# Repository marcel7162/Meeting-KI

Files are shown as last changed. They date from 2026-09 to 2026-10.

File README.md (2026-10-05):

# Meeting-KI 🎙️🤖

Ein **ESP32-S3** mit **INMP441-Mikrofon**, das Meetings mithört, den Ton an einen
kleinen Python-Server streamt, dort automatisch transkribiert und am Ende mit
**Claude** eine Zusammenfassung schreibt.

---

## Wie es funktioniert

```
┌──────────────┐   I2S    ┌───────────────┐   WLAN / TCP   ┌────────────────────────┐
│   INMP441    │ ───────► │   ESP32-S3    │ ─────────────► │      Python-Server      │
│  (Mikrofon)  │          │  (Firmware)   │   16 kHz PCM   │                        │
└──────────────┘          └───────────────┘                │  1. Audio → WAV        │
                                                            │  2. Whisper → Text     │
                                                            │  3. Claude → Zusammen- │
                                                            │     fassung (.md)      │
                                                            └────────────────────────┘
```

1. Das **INMP441** liefert digitales Audio über I2S an den **ESP32**.
2. Die **Firmware** verbindet sich beim Einschalten mit dem WLAN und dem Server
   und **startet sofort** die Aufnahme; sie streamt durchgehend
   16-kHz-Mono-PCM per TCP an den Server.
3. Der **Server** puffert den Ton. Wird der ESP vom Strom getrennt, erkennt der
   Server den Abbruch und **beendet die Aufnahme automatisch**.
4. Dann wird das Audio als WAV gespeichert, mit **faster-whisper** lokal
   transkribiert und zu einer strukturierten Zusammenfassung verarbeitet
   (Claude oder lokal via Ollama/HuggingFace).

Transkription läuft **lokal** (Datenschutz – der Rohton verlässt dein Netz
nicht). Nur der fertige Transkript-Text geht zur Zusammenfassung an Claude.

---

## Hardware & Verkabelung

Board: **ESP32-S3 Zero** (Waveshare). Alle genutzten Signal-Pins liegen auf der
vorderen Stiftleiste (GPIO1–GPIO13); die WS2812-Status-LED ist fest onboard.

### Mikrofon (INMP441)

| INMP441 Pin | Funktion | ESP32-S3 Zero |
|---|---|---|
| VDD | 3,3 V | 3V3 |
| GND | Masse | GND |
| SCK | I2S Bit-Clock (BCLK) | GPIO 4 |
| WS | I2S Word-Select (LRCLK) | GPIO 5 |
| SD | I2S Daten (DOUT) | GPIO 6 |
| L/R | Kanalwahl | GPIO 3 |

Der **L/R-Pin wird hier vom ESP32 über GPIO3 getrieben** (nicht fest an GND).
Die Firmware legt GPIO3 auf **LOW** = linker Kanal (passend zur I2S-Konfig). Wenn
du lieber fest verdrahten willst, kannst du `L/R` auch direkt an GND legen – dann
ist GPIO3 frei.

### Bedienung: nur über Strom (keine Knöpfe)

- **Strom an** → der ESP verbindet sich mit WLAN und Server und **startet sofort
  die Aufnahme**, streamt dann durchgehend.
- **Strom weg** (Akku/USB trennen) → der Server erkennt den Abbruch und
  **beendet + wertet die Aufnahme automatisch aus** (WAV + Transkript +
  Zusammenfassung).

Es gibt keine Taster. Ein „Einschalten bis Ausschalten" = ein Meeting.

### Status-LED (WS2812, onboard auf GPIO21)

| Farbe | Bedeutung |
|---|---|
| 🔴 rot blinkend | kein WLAN |
| 🟠 orange blinkend | WLAN ok, aber kein Server |
| 🔴 rot (dauerhaft) | verbunden, Aufnahme läuft / streamt |

> Alle GPIO-Nummern (und Helligkeit/Farblogik) sind in `firmware/src/config.h`
> konfigurierbar. Nutzt du ein anderes Board ohne WS2812, setze
> `STATUS_LED_IS_WS2812 0` (einfache Ein/Aus-LED) oder `STATUS_LED_PIN -1` (aus).

**Wichtig:** Das INMP441 wird mit **3,3 V** betrieben, nicht mit 5 V.

### Alternatives Board: ESP32-C3 Super Mini

Funktioniert genauso (WLAN + 1× I2S). Unterschiede: andere Pins und die
**einfache Onboard-LED auf GPIO8 (active-low)** statt WS2812.

| Signal | ESP32-C3 Super Mini |
|---|---|
| INMP441 SCK | GPIO 4 |
| INMP441 WS | GPIO 5 |
| INMP441 SD | GPIO 6 |
| INMP441 L/R | GPIO 3 |
| Status-LED | GPIO 8 (onboard, active-low) |

In `firmware/src/config.h` die C3-Werte eintragen (Vorlage steht im unteren Teil
von `config.h.example`), insbesondere:
`STATUS_LED_IS_WS2812 0`, `STATUS_LED_ACTIVE_LOW 1`, `STATUS_LED_PIN 8`.
Flashen mit dem passenden Board-Env:

```bash
pio run -e esp32-c3-supermini --target upload
```

> VDD des INMP441 weiterhin an **3,3 V**.

---

## Teil 1 – Firmware (ESP32-S3 Zero)

Die Firmware ist ein [PlatformIO](https://platformio.org/)-Projekt (Board-Env
`esp32-s3-zero`).

```bash
cd firmware
cp src/config.h.example src/config.h   # dann config.h ausfüllen
# WLAN-Zugang und Server-IP in config.h eintragen
pio run --target upload
pio device monitor        # zum Mitlesen der seriellen Ausgabe
```

> **Flashen klappt nicht?** Der ESP32-S3 Zero lässt sich in den Download-Modus
> zwingen: **BOOT gedrückt halten**, kurz **RESET** tippen (oder USB einstecken),
> BOOT loslassen – dann erneut `pio run --target upload`.

In `src/config.h` trägst du ein:
- `WIFI_SSID` / `WIFI_PASSWORD` – dein WLAN
- `SERVER_HOST` – IP-Adresse des Rechners, auf dem der Python-Server läuft
- `SERVER_PORT` – Port (Standard `8888`)

Die Firmware verbindet sich automatisch wieder, wenn WLAN oder Server-Verbindung
abbrechen. Die Onboard-LED zeigt den Status (siehe Kommentare in `main.cpp`).

---

## Teil 2 – Server (Python)

> **Python-Version beachten:** `faster-whisper` braucht `ctranslate2`, das nur
> für **64-bit-Python 3.9–3.12** fertige Pakete hat. Mit **Python 3.13/3.14**
> oder 32-bit-Python schlägt `pip install` fehl (siehe
> [Problembehebung](#problembehebung)). Prüfen mit `python --version`.

**Windows** (PowerShell), Python von https://www.python.org/ vorausgesetzt:

```powershell
cd server
python -m venv .venv
.\.venv\Scripts\Activate.ps1
pip install -r requirements.txt

copy .env.example .env     # dann .env ausfüllen (ANTHROPIC_API_KEY!)
python server.py
```

> Falls PowerShell das Aktivieren blockiert („… kann nicht geladen werden …"),
> einmalig erlauben:
> `Set-ExecutionPolicy -Scope CurrentUser RemoteSigned`

**macOS / Linux:**

```bash
cd server
python3 -m venv .venv && source .venv/bin/activate
pip install -r requirements.txt

cp .env.example .env       # dann .env ausfüllen (ANTHROPIC_API_KEY!)
python server.py
```

In `.env` trägst du ein:
- `ENABLE_SUMMARY` – `true`/`false` (Zusammenfassung an/aus)
- `SUMMARY_BACKEND` – `claude` | `huggingface` | `none` (siehe unten)
- `ANTHROPIC_API_KEY` – Claude-Schlüssel (nur bei `SUMMARY_BACKEND=claude`)
- `WHISPER_MODEL` – z. B. `base`, `small`, `medium` (Standard: `small`)
- weitere Optionen siehe `.env.example`

### Zusammenfassungs-Backend wählen

| `SUMMARY_BACKEND` | Was passiert | Claude nötig? | Qualität | Zusätzliches Setup |
|---|---|---|---|---|
| `claude` | strukturierte Zusammenfassung via Anthropic-API | ja (API-Key) | ★★★★ | – |
| `ollama` | starkes lokales LLM, **strukturiert** (Überblick, Entscheidungen, To-dos) | **nein** | ★★★☆ | Ollama + Modell |
| `huggingface` | kleines lokales Modell, kompakt & **unstrukturiert** | **nein** | ★★ | `requirements-local-summary.txt` |
| `none` | keine Zusammenfassung, nur Transkript | nein | – | – |

Für **starke, strukturierte Zusammenfassungen ohne Claude** ist `ollama`
die beste Wahl (siehe nächster Abschnitt).

> **Nur transkribieren:** `ENABLE_SUMMARY=false` (oder `SUMMARY_BACKEND=none`) –
> dann entsteht nur das Transkript, kein KI-Aufruf. Die Transkription läuft
> ohnehin komplett lokal (faster-whisper).

### Starke lokale Zusammenfassung ohne Claude (empfohlen: Ollama)

Das `ollama`-Backend nutzt ein echtes Instruct-LLM lokal und liefert dieselbe
strukturierte Gliederung wie Claude (Überblick, Entscheidungen, To-dos …) –
ohne Internet und ohne API-Key. Es braucht **keine** zusätzlichen Python-Pakete.

1. **Ollama installieren:** https://ollama.com/download
2. **Modell laden** (einmalig):
   ```bash
   ollama pull qwen2.5:14b-instruct
   ```
3. In `.env`:
   - `SUMMARY_BACKEND=ollama`
   - `OLLAMA_MODEL=qwen2.5:14b-instruct` (Standard)

Das war's – danach wie gewohnt `python process_file.py ...` bzw. den Server nutzen.

**Andere Modelle:** leichter/schneller `qwen2.5:7b-instruct` oder `llama3.1:8b`;
stärker (mehr RAM/VRAM, langsamer) `qwen2.5:32b-instruct` (jeweils vorher
`ollama pull`). Faustregel RAM/VRAM: 7B ≈ 6–8 GB, 14B ≈ 10–12 GB, 32B ≈ 20 GB+.
Auf CPU läuft es, dauert aber spürbar länger – für lange Meetings fasst das
Backend automatisch abschnittsweise zusammen (Map-Reduce).

### Komplett ohne Claude (kleines Modell via HuggingFace)

Alternativ ein kleines, schnelles Summarizer-Modell lokal (ohne Ollama):

```bash
pip install -r requirements-local-summary.txt   # transformers + torch (mehrere hundert MB)
```

In `.env`: `SUMMARY_BACKEND=huggingface` (optional `HF_SUMMARY_MODEL=...`).

> ⚠️ **Erwartung:** Dieses kleine Modell liefert nur eine kompakte,
> **unstrukturierte** Zusammenfassung – keine Abschnitte wie Entscheidungen/
> To-dos. Für Struktur ohne Claude nimm `ollama`.

Für **Sprecher-Trennung** zusätzlich `ENABLE_DIARIZATION=true` +
`HUGGINGFACE_TOKEN` setzen (siehe nächster Abschnitt) – sie lässt sich mit
jedem Zusammenfassungs-Backend kombinieren.

### Bedienung

Der Server nimmt die TCP-Verbindung des ESP32 automatisch an. Gesteuert wird
**über den Strom**:

- **ESP einschalten** → verbindet sich und nimmt sofort auf (LED **rot**).
- **ESP vom Strom trennen** → der Server erkennt den Abbruch (sauberes
  TCP-Ende oder Watchdog nach ein paar Sekunden ohne Audio) und erzeugt
  automatisch WAV + Transkript + Zusammenfassung.

Ersatzweise geht es auch über die Tastatur im Server-Fenster:

| Taste | Aktion |
|---|---|
| `s` + Enter | Aufnahme **starten** |
| `e` + Enter | Aufnahme **beenden** → WAV + Transkript + Zusammenfassung |
| `q` + Enter | Server beenden |

Nach dem Stoppen entstehen:
- `recordings/meeting_<zeitstempel>.wav` – der Mitschnitt
- `summaries/meeting_<zeitstempel>.md` – Transkript **und** Zusammenfassung

### Vorhandene Aufnahme nachträglich verarbeiten

Du kannst eine bereits aufgenommene WAV **ohne neue Aufnahme** erneut durch die
Pipeline schicken (z. B. nachdem die Transkription beim ersten Mal fehlschlug,
oder um nachträglich eine Zusammenfassung zu erzeugen). Die Ergebnisse landen
wie gewohnt in `summaries/`.

```powershell
# eine bestimmte Datei
python process_file.py recordings/meeting_20261001_152504.wav

# alle Aufnahmen, zu denen es noch kein summaries/*.md gibt
python process_file.py --all
```

**Transkript-Cache (wichtig bei langer Transkription):** Beim ersten Lauf wird
das Transkript als `summaries/<name>.segments.json` gespeichert. Folgeläufe
**transkribieren nicht erneut** (das spart die 20 Minuten Whisper), sondern laden
den Cache in Sekunden. So kannst du Sprecher-Trennung und Zusammenfassung
getrennt und beliebig oft laufen lassen:

```powershell
# NUR Sprecher-Trennung nachtraeglich (Transkript aus Cache, ohne Zusammenfassung)
python process_file.py --diarize-only recordings/meeting_...wav

# NUR neu zusammenfassen (Transkript aus Cache, ohne Sprecher-Trennung)
python process_file.py --summary-only recordings/meeting_...wav

# Cache ignorieren und wirklich neu transkribieren
python process_file.py --no-cache recordings/meeting_...wav
```

Die Einstellungen aus `.env` gelten sonst genauso (z. B. `ENABLE_SUMMARY`,
`WHISPER_MODEL`, `ENABLE_DIARIZATION`). Der Server muss dafür **nicht** laufen.
Es funktioniert mit jeder 16-kHz-Mono-WAV – auch mit Aufnahmen aus anderer
Quelle.

### Wer spricht? (optionale Sprecher-Trennung)

Der Server kann das Transkript in **SPRECHER_1, SPRECHER_2, …** aufteilen
(sog. Diarization). Das erkennt *unterschiedliche Stimmen* – **keine Namen** –
und ist mit einem einzelnen, weiter entfernten MEMS-Mikrofon nur begrenzt
genau (Nachhall, Abstand, gleichzeitiges Sprechen).

So aktivierst du es:

```bash
pip install -r requirements-diarization.txt   # torch etc. – mehrere hundert MB
```

Dann in `.env`:
- `ENABLE_DIARIZATION=true`
- `HUGGINGFACE_TOKEN=...` – Token von https://huggingface.co/settings/tokens
- Auf huggingface.co die Nutzungsbedingungen des Modells
  **`pyannote/speaker-diarization-3.1`** akzeptieren (einmalig).

Ist alles vorhanden, erscheinen im Transkript und in der Zusammenfassung die
Sprecher-Labels. Schlägt die Trennung fehl, fällt der Server automatisch auf
ein Transkript ohne Sprecher zurück.

---

## Netzwerk: IP-Adresse & Firewall (Windows)

Der ESP32 muss die **lokale IP-Adresse** des Windows-Rechners kennen, auf dem
`server.py` läuft. Beide Geräte müssen im **selben 2,4-GHz-WLAN** sein.

### 1. Lokale IP herausfinden

Eingabeaufforderung (`cmd`) oder PowerShell öffnen und eingeben:

```powershell
ipconfig
```

Beim WLAN-Adapter („Drahtlos-LAN-Adapter WLAN") die Zeile **IPv4-Adresse**
suchen, z. B. `192.168.1.100`. Genau diese Adresse kommt in die Firmware:

```c
// firmware/src/config.h
#define SERVER_HOST  "192.168.1.100"   // deine IPv4-Adresse
#define SERVER_PORT  8888
```

> Es ist die lokale Adresse (`192.168.…` oder `10.…`) – **nicht** die
> Internet-IP von „wieistmeineip" und **nicht** `127.0.0.1`.

### 2. Firewall-Freigabe

Beim ersten `python server.py` fragt Windows meist:
„**Zugriff auf dieses Netzwerk zulassen?**" → für **private Netzwerke zulassen**.
Dann darf der ESP32 auf Port `8888` zugreifen.

Keine Abfrage erschienen oder versehentlich blockiert? Regel manuell anlegen
(PowerShell **als Administrator**):

```powershell
New-NetFirewallRule -DisplayName "Meeting-KI" -Direction Inbound `
  -Protocol TCP -LocalPort 8888 -Action Allow -Profile Private
```

### 3. IP bleibt nicht stabil? (feste IP)

Der Router vergibt IP-Adressen per DHCP – nach einem Neustart kann der Rechner
eine andere IP bekommen, und der ESP32 findet den Server nicht mehr. Abhilfe:
im Router unter **DHCP / Adressreservierung** dem Rechner (anhand seiner
MAC-Adresse, aus `ipconfig /all`) eine **feste IP** zuweisen. Danach bleibt
`SERVER_HOST` konstant.

### 4. Verbindung testen

- Server starten: Es erscheint „warte auf ESP32 an `0.0.0.0:8888`".
  (`0.0.0.0` ist Absicht – der Server lauscht auf allen Netzwerk-Schnittstellen.)
- ESP32 einschalten: LED wird **grün**, im Server-Fenster erscheint
  „ESP32 verbunden: 192.168.x.x".
- Kommt keine Verbindung: gleiches WLAN? Gast-WLAN/Client-Isolation aus?
  IP korrekt? Firewall offen?

---

## Erste Inbetriebnahme (Checkliste)

1. INMP441 wie oben verdrahten.
2. `server/.env` mit deinem `ANTHROPIC_API_KEY` befüllen und `python server.py`
   starten. Die lokale IP des Rechners notieren (`ip addr` / `ipconfig`).
3. `firmware/src/config.h` mit WLAN und dieser Server-IP befüllen und flashen.
4. ESP mit Strom versorgen. Im Server-Fenster erscheint „ESP32 verbunden" und
   „ESP: START (automatisch)"; die LED wird rot = Aufnahme läuft.
5. Meeting sprechen → danach den **ESP vom Strom trennen**. Der Server beendet
   automatisch und schreibt die Zusammenfassung nach `summaries/`.

---

## Problembehebung

### `pip install` scheitert an `ctranslate2` / `faster-whisper`

Fehlermeldung sinngemäß: *„Cannot install … faster-whisper … no matching
distributions available for your environment: ctranslate2"* bzw.
*„ResolutionImpossible"*.

**Ursache:** `faster-whisper` nutzt `ctranslate2`, und dafür gibt es nur fertige
Pakete für **64-bit-Python 3.9–3.12**. Mit **Python 3.13/3.14** oder einem
32-bit-Python findet pip kein passendes Paket.

**Prüfen:**

```powershell
python --version
python -c "import platform; print(platform.architecture()[0], platform.machine())"
```

Ist die Version `3.13`/`3.14` oder steht dort `32bit`, ist das die Ursache.

**Lösung (Windows): Python 3.12 (64-bit) nutzen**

1. Python 3.12 (64-bit) installieren von
   https://www.python.org/downloads/release/python-3129/
   (Datei „Windows installer (64-bit)"). Beim Installieren **„Add python.exe to
   PATH"** anhaken.
2. Alte venv löschen und mit 3.12 neu anlegen. Der [Python Launcher](https://docs.python.org/3/using/windows.html#python-launcher-for-windows)
   `py` wählt gezielt die Version:

   ```powershell
   cd server
   rmdir /s /q .venv            # in PowerShell: Remove-Item -Recurse -Force .venv
   py -3.12 -m venv .venv
   .\.venv\Scripts\Activate.ps1
   python --version             # sollte 3.12.x zeigen
   pip install --upgrade pip
   pip install -r requirements.txt
   ```

Danach installiert `faster-whisper` sauber durch.

> macOS/Linux: analog eine 3.12 anlegen, z. B. `python3.12 -m venv .venv`
> (ggf. vorher über den Paketmanager / pyenv installieren).

### Transkription: `open() got an unexpected keyword argument 'metadata_errors'`

**Ursache:** faster-whisper liest Audio normalerweise über **PyAV (`av`)** ein;
je nach `av`-Version passt der Aufruf `av.open(..., metadata_errors=...)` nicht
zur installierten faster-whisper-Version (in beide Richtungen möglich).

**Lösung:** Dieses Projekt liest WAV-Dateien inzwischen **ohne PyAV** direkt mit
NumPy ein – der Fehler kann damit nicht mehr auftreten. Einfach aktuellen Stand
holen:

```powershell
git pull
pip install -r requirements.txt   # stellt sicher, dass numpy vorhanden ist
```

### Sprecher-Trennung: `libtorchcodec_core*.dll` / FFmpeg-Fehler

**Ursache:** pyannote lädt Audio sonst über `torchaudio → torchcodec`, das
installiertes **FFmpeg** braucht (auf Windows oft nicht vorhanden).

**Lösung:** Dieses Projekt übergibt pyannote inzwischen das Audio **direkt als
Tensor** (selbst mit NumPy geladen) – kein torchcodec/FFmpeg nötig. Einfach
aktuellen Stand holen (`git pull`) und erneut ausführen, z. B.:

```powershell
python process_file.py --diarize-only recordings/meeting_...wav
```

### Warnung: „huggingface_hub … symlinks … not supported"

Nur eine **Warnung**, kein Fehler – das Whisper-Modell wird trotzdem geladen
(nur etwas mehr Speicherverbrauch im Cache). Wegklicken kannst du sie, indem du
entweder den **Entwicklermodus** von Windows aktivierst (Einstellungen → Für
Entwickler) oder die Warnung unterdrückst:

```powershell
setx HF_HUB_DISABLE_SYMLINKS_WARNING 1
```

(neues Terminal öffnen, damit die Variable greift).

### ESP32 verbindet sich nicht mit dem Server

Siehe [Netzwerk: IP-Adresse & Firewall (Windows)](#netzwerk-ip-adresse--firewall-windows):
gleiches 2,4-GHz-WLAN, richtige lokale IP in `config.h`, Firewall-Port 8888 offen,
kein Gast-WLAN mit Client-Isolation.

---

## Datenschutz & rechtlicher Hinweis

Das Mitschneiden von Gesprächen und Meetings unterliegt rechtlichen Regeln
(in Deutschland u. a. § 201 StGB, DSGVO). **Informiere alle Teilnehmenden und
hole ihr Einverständnis ein, bevor du aufnimmst.** Dieses Projekt ist für den
eigenen, erlaubten Gebrauch gedacht.

---

## Projektstruktur

```
Meeting-KI/
├── firmware/                 # ESP32-S3 PlatformIO-Projekt
│   ├── platformio.ini
│   └── src/
│       ├── main.cpp          # I2S-Aufnahme + WLAN + TCP-Streaming (Auto-Start)
│       └── config.h.example  # Vorlage für WLAN/Server/Pins-Konfiguration
└── server/                   # Python-Server
    ├── requirements.txt
    ├── requirements-diarization.txt  # optionale Pakete für Sprecher-Trennung
    ├── .env.example
    ├── server.py             # TCP-Empfang (Framing) + Aufnahmesteuerung
    ├── pipeline.py           # gemeinsame Verarbeitung: WAV -> Transkript -> MD
    ├── process_file.py       # vorhandene WAV nachträglich verarbeiten
    ├── transcribe.py         # lokale Transkription (faster-whisper)
    ├── diarize.py            # optionale Sprecher-Trennung (pyannote/HuggingFace)
    ├── prompts.py            # gemeinsame Prompts (Claude + Ollama)
    ├── summarize.py          # Zusammenfassung via Claude
    ├── summarize_ollama.py   # starke lokale Zusammenfassung via Ollama (ohne Claude)
    ├── summarize_local.py    # kleine lokale Zusammenfassung via HuggingFace
    ├── requirements-local-summary.txt  # optionale Pakete für HF-Zusammenfassung
    ├── recordings/           # gespeicherte WAV-Dateien
    └── summaries/            # Transkripte + Zusammenfassungen
```

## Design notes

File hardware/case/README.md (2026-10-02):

# Gehäuse (3D-Druck) – ESP32-C3 Super Mini + INMP441 + Akku

Parametrisches Gehäuse für die Meeting-KI-Hardware:
**ESP32-C3 Super Mini** (ohne Pinleiste) + **INMP441**-Mikrofon (ohne Pinleiste)
+ **LiPo-Akku 20 × 27 × 5 mm**.

Außenmaße: **33 × 25 × 18 mm** (Unterteil 16,5 mm + Deckel 1,5 mm).

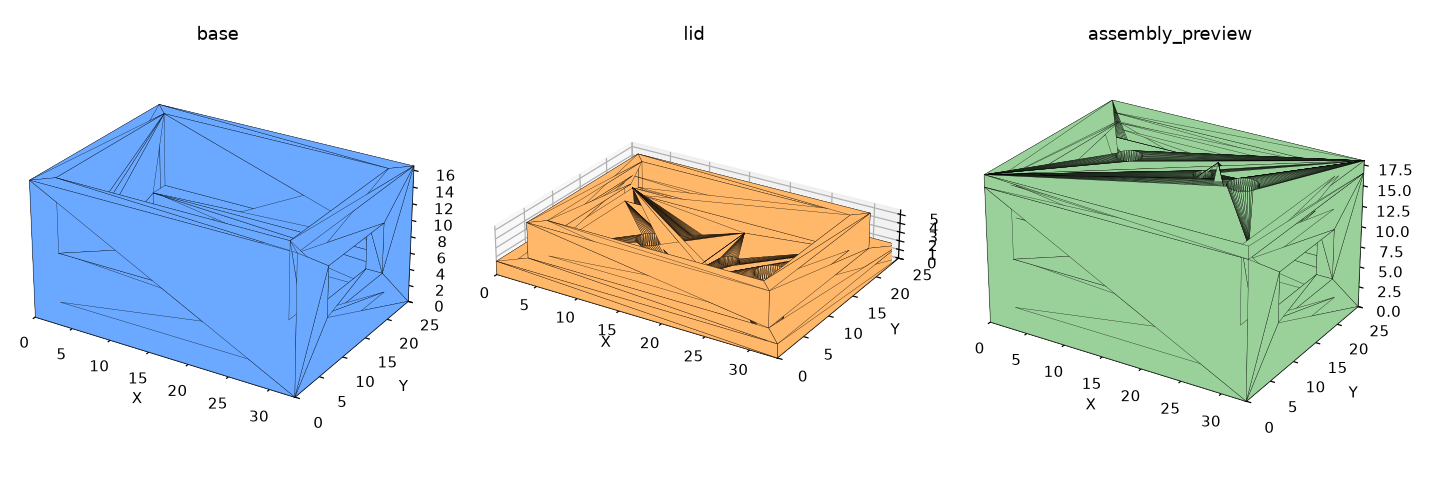
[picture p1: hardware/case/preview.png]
Vorschau


## Dateien

| Datei | Zweck |
|---|---|
| `meeting_ki_case.FCMacro` | **Parametrisches FreeCAD-Macro** – hier alle Maße ändern |
| `generate_case.py` | Erzeugt die STLs ohne FreeCAD (trimesh) – gleiche Maße |
| `base.stl` | Unterteil (drucken wie es liegt, offene Seite nach oben) |
| `lid.stl` | Deckel (flache Oberseite liegt auf dem Druckbett, Rand nach oben) |
| `assembly_preview.stl` | nur zur Ansicht (Deckel aufgesetzt) |

## In FreeCAD öffnen/ändern

1. FreeCAD starten → Menü **Macro → Macros… → „meeting_ki_case.FCMacro"** →
   **Ausführen**. Es entstehen die Körper „Base" und „Lid", und die STLs werden
   neben das Macro exportiert.
2. Maße ändern: oben im Macro die `#define`-ähnlichen Variablen anpassen
   (z. B. `IN_L`, `IN_W`, `IN_H`, `BATT_H`, `USB_W/H/Z`, `WALL`) und erneut
   ausführen.

Alternativ ohne FreeCAD neue STLs erzeugen:
```bash
pip install trimesh manifold3d numpy
python generate_case.py
```

## Aufbau / Montage

```
  Deckel  ── Schallloch über dem Mikrofon, Löcher für Taster + LED
            └ INMP441 liegt in der Tasche an der Deckelunterseite
  ─────────────────────────────────
  ESP32-C3 Super Mini  ── liegt auf zwei Auflageschienen (lange Wände)
  ─────────────────────────────────
  LiPo-Akku 27×20×5    ── liegt unten auf dem Boden
  ─────────────────────────────────  Unterteil
```

- **USB-C** zeigt zur Schmalseite mit dem Ausschnitt (Laden/Flashen).
- Das **INMP441** kommt mit der Schallöffnung nach oben in die Deckeltasche; das
  3-mm-Loch im Deckel liegt darüber. Mit etwas Heißkleber/Doppelklebeband fixieren.
- Verkabelung mit dünnen Litzen (Projekt ist „ohne Pinleiste" ausgelegt).

## ⚠️ Bitte vor dem Druck prüfen (Maße variieren je nach Hersteller)

Ich habe mit typischen Maßen gerechnet – **miss deine echten Teile nach** und
passe sie im Macro an:

- **ESP32-C3 Super Mini**: Platine ~22,5 × 18 mm; **USB-C-Buchse** Lage/Höhe →
  bestimmt `USB_Z`, `USB_W`, `USB_H`. Die Buchse sitzt an der Schmalseite.
- **INMP441 ohne Pinleiste**: Platine ~15 × 13 mm → `MIC_L`, `MIC_W`; Lage der
  Schallöffnung → `MIC_OFFSET_X` (Loch soll genau darüber liegen).
- **Akku**: bestätige **27 × 20 × 5 mm** (L×B×H) inkl. Schutzschaltung; Kabel­abgang
  braucht evtl. etwas Platz.
- **Taster/LED**: `BTN_OFFSET_X`, `LED_OFFSET_X` an deine tatsächliche Bauteillage
  anpassen (oder Löcher weglassen).

## Hinweise zum Druck

- Material PLA/PETG, 0,2 mm Schicht, 3 Perimeter – kein Support nötig
  (Unterteil offen nach oben, Deckel flach).
- Der Deckel ist als **Reibschluss-Steckdeckel** ausgelegt (`RIM_CLEAR = 0,3 mm`).
  Sitzt er zu stramm/locker, `RIM_CLEAR` anpassen.
- **LiPo-Sicherheit:** Akku nicht quetschen/durchbohren; Gehäuse nicht luftdicht
  verkleben, etwas Luft lassen. Kein Dauer-Einschluss beim Laden ohne Aufsicht.

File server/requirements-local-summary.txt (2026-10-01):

# Optionale Zusatzpakete für die lokale Zusammenfassung (SUMMARY_BACKEND=huggingface).
# Nur installieren, wenn du ohne Claude zusammenfassen willst:
#     pip install -r requirements-local-summary.txt
#
# Achtung: torch ist groß (mehrere hundert MB). Für GPU-Nutzung ggf. die passende
# torch-Variante von https://pytorch.org/ installieren.
transformers>=4.40
torch>=2.0
sentencepiece>=0.1.99     # von mT5/T5-Modellen benötigt
protobuf>=3.20            # von manchen Tokenizern benötigt

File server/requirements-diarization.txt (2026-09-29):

# Optionale Zusatzpakete für die Sprecher-Trennung (Diarization).
# Nur installieren, wenn ENABLE_DIARIZATION=true genutzt werden soll:
#     pip install -r requirements-diarization.txt
#
# Achtung: torch ist groß (mehrere hundert MB bis >1 GB). Für GPU-Nutzung ggf.
# die passende torch-Variante von https://pytorch.org/ installieren.
pyannote.audio>=3.1
torch>=2.0
torchaudio>=2.0

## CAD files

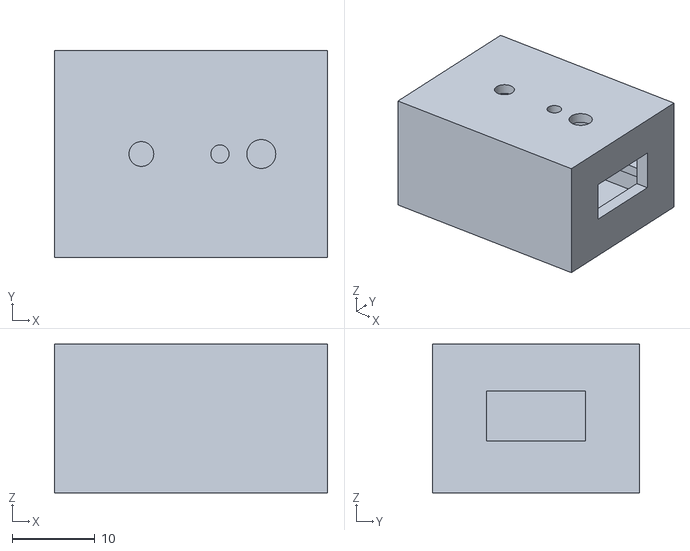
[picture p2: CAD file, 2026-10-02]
hardware/case/assembly_preview.stl
33.0 x 25.0 x 18.0

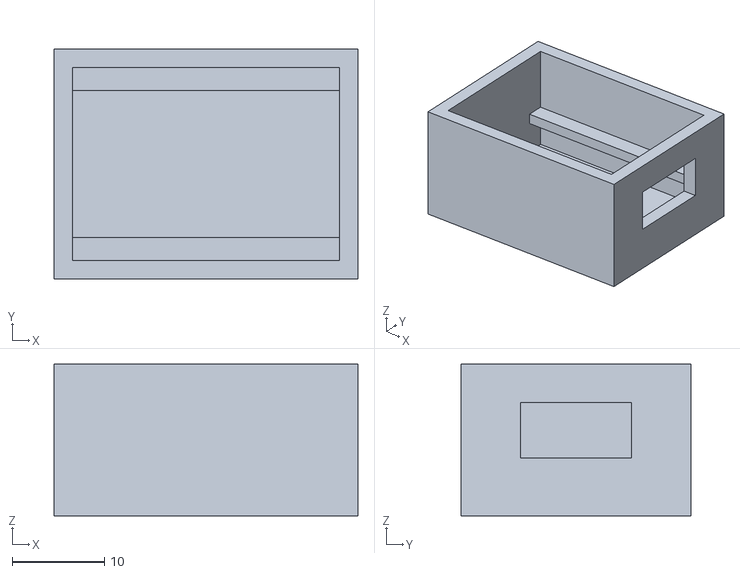
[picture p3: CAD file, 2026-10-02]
hardware/case/base.stl
33.0 x 25.0 x 16.5

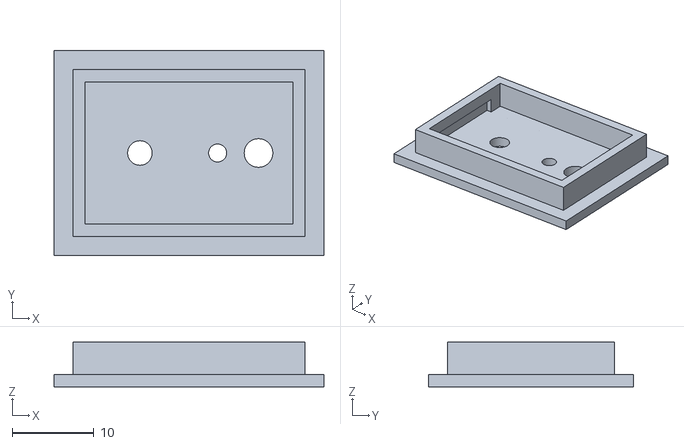
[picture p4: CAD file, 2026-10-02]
hardware/case/lid.stl
33.0 x 25.0 x 5.50

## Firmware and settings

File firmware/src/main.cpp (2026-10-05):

// -----------------------------------------------------------------------------
// Meeting-KI – ESP32 Firmware (automatischer Betrieb)
//
// Verhalten:
//   Strom an  -> WLAN + Server verbinden -> SOFORT Aufnahme starten und
//                16-kHz-Mono-PCM per TCP streamen.
//   Strom weg -> der ESP ist aus; der Server erkennt den Abbruch und beendet
//                die Aufnahme automatisch (Transkription + Zusammenfassung).
//
// Keine Knöpfe, kein Deep Sleep. Ein Tonstream = ein Meeting.
//
// Übertragungsprotokoll (ein TCP-Stream, mit Framing):
//   Jeder Frame:  [1 Byte Typ][4 Byte Länge, little-endian][Nutzdaten]
//     Typ 0x01 = AUDIO   -> Nutzdaten = 16-Bit-PCM (mono, little-endian)
//     Typ 0x02 = CONTROL -> Nutzdaten = 1 Byte Kommando (0x10=START, 0x11=STOP)
//
// Status-LED:
//   rot blinkend    = kein WLAN
//   orange blinkend = WLAN ok, aber kein Server
//   rot (dauerhaft) = verbunden, Aufnahme läuft / streamt
// -----------------------------------------------------------------------------
#include <Arduino.h>
#include <WiFi.h>
#include <WiFiClient.h>
#include <driver/i2s.h>

#include "config.h"

// ---- Protokoll-Konstanten (müssen mit dem Server übereinstimmen) ------------
static const uint8_t MSG_AUDIO   = 0x01;
static const uint8_t MSG_CONTROL = 0x02;
static const uint8_t CTRL_START  = 0x10;
static const uint8_t CTRL_STOP   = 0x11;

// I2S-Port und Puffergrößen
static const i2s_port_t I2S_PORT = I2S_NUM_0;
static const int        DMA_BUF_COUNT = 8;
static const int        DMA_BUF_LEN   = 256;   // Samples pro DMA-Puffer
static const int        SAMPLES_PER_READ = 512;

static WiFiClient client;

static int32_t raw_samples[SAMPLES_PER_READ];
static int16_t pcm_samples[SAMPLES_PER_READ];

static bool streaming = false;  // true = mit Server verbunden und Aufnahme läuft

// ---------------------------------------------------------------------------
// Status-LED (WS2812-RGB oder einfache Ein/Aus-LED)
// ---------------------------------------------------------------------------
static void ledColor(uint8_t r, uint8_t g, uint8_t b) {
#if STATUS_LED_PIN >= 0
#if STATUS_LED_IS_WS2812
  neopixelWrite(STATUS_LED_PIN, r, g, b);
#else
  bool on = (r || g || b);
  digitalWrite(STATUS_LED_PIN, (on ^ (bool)STATUS_LED_ACTIVE_LOW) ? HIGH : LOW);
#endif
#else
  (void)r; (void)g; (void)b;
#endif
}

static void ledOff() { ledColor(0, 0, 0); }
static void ledStreaming() { ledColor(LED_BRIGHTNESS, 0, 0); }  // rot

static void ledBlinkColor(uint8_t r, uint8_t g, uint8_t b, int on_ms, int off_ms) {
#if STATUS_LED_PIN >= 0
  ledColor(r, g, b);
  delay(on_ms);
  ledOff();
  delay(off_ms);
#else
  (void)r; (void)g; (void)b;
  delay(on_ms + off_ms);
#endif
}

// ---------------------------------------------------------------------------
// Framing: einen Frame an den Server senden
// ---------------------------------------------------------------------------
static bool sendFrame(uint8_t type, const uint8_t *payload, uint32_t len) {
  uint8_t header[5];
  header[0] = type;
  header[1] = (uint8_t)(len & 0xFF);
  header[2] = (uint8_t)((len >> 8) & 0xFF);
  header[3] = (uint8_t)((len >> 16) & 0xFF);
  header[4] = (uint8_t)((len >> 24) & 0xFF);

  if (client.write(header, sizeof(header)) != sizeof(header)) return false;
  if (len > 0 && client.write(payload, len) != len) return false;
  return true;
}

static bool sendControl(uint8_t command) {
  return sendFrame(MSG_CONTROL, &command, 1);
}

// ---------------------------------------------------------------------------
// I2S einrichten (RX vom INMP441)
// ---------------------------------------------------------------------------
static void setupI2S() {
  i2s_config_t i2s_config = {
      .mode = (i2s_mode_t)(I2S_MODE_MASTER | I2S_MODE_RX),
      .sample_rate = SAMPLE_RATE,
      .bits_per_sample = I2S_BITS_PER_SAMPLE_32BIT,   // INMP441: 24 Bit in 32-Bit-Frames
      .channel_format = I2S_CHANNEL_FMT_ONLY_LEFT,    // L/R-Pin auf GND -> linker Kanal
      .communication_format = I2S_COMM_FORMAT_STAND_I2S,
      .intr_alloc_flags = ESP_INTR_FLAG_LEVEL1,
      .dma_buf_count = DMA_BUF_COUNT,
      .dma_buf_len = DMA_BUF_LEN,
      .use_apll = false,
      .tx_desc_auto_clear = false,
      .fixed_mclk = 0,
  };

  i2s_pin_config_t pin_config = {
      .bck_io_num = I2S_SCK_PIN,
      .ws_io_num = I2S_WS_PIN,
      .data_out_num = I2S_PIN_NO_CHANGE,
      .data_in_num = I2S_SD_PIN,
  };

  if (i2s_driver_install(I2S_PORT, &i2s_config, 0, NULL) != ESP_OK) {
    Serial.println("[I2S] Installation fehlgeschlagen");
    return;
  }
  if (i2s_set_pin(I2S_PORT, &pin_config) != ESP_OK) {
    Serial.println("[I2S] Pin-Konfiguration fehlgeschlagen");
    return;
  }
  Serial.println("[I2S] bereit");
}

// ---------------------------------------------------------------------------
// WLAN verbinden (blockiert, bis Verbindung steht)
// ---------------------------------------------------------------------------
static void connectWiFi() {
  if (WiFi.status() == WL_CONNECTED) return;

  Serial.printf("[WiFi] verbinde mit \"%s\" ...\n", WIFI_SSID);
  WiFi.mode(WIFI_STA);
  WiFi.begin(WIFI_SSID, WIFI_PASSWORD);

  while (WiFi.status() != WL_CONNECTED) {
    ledBlinkColor(LED_BRIGHTNESS, 0, 0, 80, 80);  // rot blinkend: kein WLAN
    Serial.print(".");
  }
  Serial.printf("\n[WiFi] verbunden, IP: %s\n", WiFi.localIP().toString().c_str());
}

// ---------------------------------------------------------------------------
// Server verbinden und sofort Aufnahme starten
// ---------------------------------------------------------------------------
static bool connectServerAndStart() {
  if (client.connected()) return true;

  Serial.printf("[TCP] verbinde mit %s:%d ...\n", SERVER_HOST, SERVER_PORT);
  if (!client.connect(SERVER_HOST, SERVER_PORT)) {
    Serial.println("[TCP] Verbindung fehlgeschlagen");
    return false;
  }
  client.setNoDelay(true);
  Serial.println("[TCP] Server verbunden");

  if (!sendControl(CTRL_START)) {
    Serial.println("[TCP] START konnte nicht gesendet werden");
    client.stop();
    return false;
  }
  streaming = true;
  ledStreaming();
  Serial.println("[REC] Aufnahme gestartet (automatisch)");
  return true;
}

// ---------------------------------------------------------------------------
void setup() {
  Serial.begin(115200);
  delay(300);
  Serial.println("\n=== Meeting-KI Firmware (Auto-Start) ===");

#if STATUS_LED_PIN >= 0 && !STATUS_LED_IS_WS2812
  pinMode(STATUS_LED_PIN, OUTPUT);
#endif
  ledOff();

  // L/R-Kanalwahl des Mikrofons fest über GPIO treiben
  pinMode(MIC_LR_PIN, OUTPUT);
  digitalWrite(MIC_LR_PIN, MIC_LR_LEVEL);

  connectWiFi();
  setupI2S();
  connectServerAndStart();
}

// ---------------------------------------------------------------------------
void loop() {
  // WLAN sicherstellen
  if (WiFi.status() != WL_CONNECTED) {
    streaming = false;
    connectWiFi();
    return;
  }

  // Serververbindung sicherstellen (startet bei Erfolg automatisch eine Aufnahme)
  if (!client.connected()) {
    streaming = false;
    ledBlinkColor(LED_BRIGHTNESS, LED_BRIGHTNESS / 2, 0, 500, 500);  // orange: kein Server
    if (!connectServerAndStart()) {
      delay(1000);
      return;
    }
  }

  // Audio lesen und senden
  size_t bytes_read = 0;
  esp_err_t err = i2s_read(I2S_PORT, raw_samples, sizeof(raw_samples),
                           &bytes_read, portMAX_DELAY);
  if (err != ESP_OK || bytes_read == 0) {
    return;
  }

  int n = bytes_read / sizeof(int32_t);
  for (int i = 0; i < n; i++) {
    int32_t v = raw_samples[i] >> MIC_SHIFT;
    if (v > 32767) v = 32767;
    else if (v < -32768) v = -32768;
    pcm_samples[i] = (int16_t)v;
  }

  if (!sendFrame(MSG_AUDIO, (const uint8_t *)pcm_samples, n * sizeof(int16_t))) {
    Serial.println("[TCP] Sendefehler – Verbindung wird zurückgesetzt");
    client.stop();
    streaming = false;
  }
}

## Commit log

2026-09-29 Meeting-KI: ESP32-S3 + INMP441 Mikrofon mit Claude-Zusammenfassung
    Vollständiges Starterprojekt, das Meetings mithört und am Ende automatisch
    eine Zusammenfassung erstellt:
    - firmware/: ESP32-S3 PlatformIO-Projekt. Nimmt Audio vom INMP441 (I2S)
    auf und streamt 16-kHz-Mono-PCM per TCP an den Server. WLAN-Reconnect,
    Status-LED, konfigurierbar über config.h.
    - server/: Python-Server. Empfaengt den PCM-Stream, zeichnet Meetings per
    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
2026-09-29 Steuerung ueber Knoepfe am ESP32 + optionale Sprecher-Trennung
    Knopf-Steuerung:
    - Zwei Taster am ESP32 (START/STOP) starten/beenden die Aufnahme, mit
    Entprellung. Audio wird nur waehrend der Aufnahme gestreamt.
    - Neues Framing-Protokoll auf der TCP-Verbindung (Typ + Laenge + Nutzdaten),
    damit AUDIO- und CONTROL-Nachrichten (START/STOP) sauber getrennt sind.
    - Server parst Frames, reagiert auf START/STOP und verarbeitet Aufnahmen in
    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
2026-10-01 Anpassung an ESP32-S3 Zero: WS2812-Status-LED, GPIO3 als L/R, Windows-Netzwerkanleitung
    Firmware:
    - Status-LED auf WS2812 (Onboard GPIO21) umgestellt: Farbstatus
    (rot=kein WLAN, orange=kein Server, gruen=bereit, rot dauerhaft=Aufnahme)
    ueber neopixelWrite; weiterhin per STATUS_LED_IS_WS2812/STATUS_LED_PIN auf
    einfache LED oder aus umschaltbar. Helligkeit via LED_BRIGHTNESS.
    - L/R-Kanalwahl des INMP441 jetzt per GPIO3 getrieben (MIC_LR_PIN/MIC_LR_LEVEL,
    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
2026-10-01 README: Problembehebung fuer ctranslate2/faster-whisper-Installationsfehler
    - Neuer Abschnitt "Problembehebung": pip-Fehler bei faster-whisper/ctranslate2
    erklaert (nur 64-bit-Python 3.9-3.12 unterstuetzt), mit Pruef-Befehlen und
    Schritt-fuer-Schritt-Loesung (Python 3.12 64-bit + venv neu anlegen).
    - Hinweis zur Python-Version direkt bei der Server-Installation.
    - Verweis auf die Netzwerk-/Firewall-Hinweise bei Verbindungsproblemen.
    Claude-Session: https://claude.ai/code/session_01SaVV543EKwCNw5aX4ngmXc
2026-10-01 Fix av-Abhaengigkeit + reiner Transkriptionsmodus ohne Claude
    - requirements.txt: av>=11.0 explizit aufgenommen. Behebt den Fehler
    "open() got an unexpected keyword argument 'metadata_errors'" beim
    Transkribieren (zu alte PyAV-Version ohne metadata_errors-Support).
    - Neuer Schalter ENABLE_SUMMARY (Standard true). Bei false oder fehlendem
    ANTHROPIC_API_KEY wird die Claude-Zusammenfassung sauber uebersprungen statt
    einen Fehler zu werfen; es entsteht ein reines lokales Transkript.
    - Startmeldung und Markdown-Ausgabe entsprechend angepasst (Status
    Zusammenfassung ja/nein).
    - .env.example: ENABLE_SUMMARY ergaenzt, API-Key als optional markiert.
    - README: Hinweis auf rein lokale Transkr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
2026-10-01 Pipeline in gemeinsames Modul ausgelagert + process_file.py zum Nachverarbeiten
    - Neues pipeline.py buendelt die Verarbeitung (WAV -> Transkript -> optional
    Sprecher-Trennung -> optional Claude-Zusammenfassung -> Markdown). Server und
    Skript nutzen denselben Code.
    - server.py nutzt jetzt pipeline.save_wav/process_wav/startup_hint; der Live-
    Pfad verhaelt sich unveraendert.
    - Neues process_file.py: vorhandene WAV ohne neue Aufnahme durch die Pipeline
    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
2026-10-01 WAV-Decoding ohne PyAV: behebt av metadata_errors-Fehler
    faster-whisper liest Audio sonst ueber PyAV ein; je nach av-Version passt
    av.open(..., metadata_errors=...) nicht zur faster-whisper-Version und wirft
    "open() got an unexpected keyword argument 'metadata_errors'".
    - transcribe.py liest PCM-WAV jetzt selbst mit wave + numpy (8/16/32-bit,
    mono/stereo, Resampling auf 16 kHz) und uebergibt faster-whisper ein
    float32-Array statt eines Dateipfads. Damit entfaellt av.open komplett.
    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
2026-10-01 Lokale Zusammenfassung via HuggingFace (ohne Claude) als Backend-Option
    - Neues SUMMARY_BACKEND (claude | huggingface | none). pipeline._make_summary
    waehlt das Backend; summarize-Import ist jetzt lazy.
    - summarize_local.py: lokale Zusammenfassung mit transformers-Summarization-
    Pipeline (deutsches mT5-Standardmodell, konfigurierbar ueber HF_SUMMARY_MODEL),
    inkl. Chunking langer Transkripte und Gesamtueberblick. Laeuft komplett lokal.
    - requirements-local-summary.txt (transformers, torch, sentencepiece, protobuf).
    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
2026-10-01 Starkes lokales Zusammenfassungs-Backend via Ollama (strukturiert, ohne Claude)
    - Neues SUMMARY_BACKEND=ollama: nutzt ein lokales Instruct-LLM ueber die
    Ollama-HTTP-API und liefert dieselbe strukturierte Gliederung wie Claude.
    Keine zusaetzlichen Python-Pakete noetig (nur Ollama selbst), Kommunikation
    ueber urllib (stdlib).
    - summarize_ollama.py: Single-Pass fuer kurze, Map-Reduce (abschnittsweise
    Notizen + finaler Reduce) fuer lange Transkripte. Konfigurierbar ueber
    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
2026-10-02 Unterstuetzung fuer ESP32-C3 Super Mini als alternatives Board
    - Firmware: Status-LED-Ausgabe kann jetzt active-low (STATUS_LED_ACTIVE_LOW)
    fuer einfache Onboard-LEDs. WS2812-Pfad unveraendert.
    - config.h.example: STATUS_LED_ACTIVE_LOW ergaenzt + kommentierter C3-Super-Mini-
    Block (Pins 4/5/6 I2S, 3 L/R, 10/7 Taster, LED GPIO8 active-low).
    - platformio.ini: zweites Env esp32-c3-supermini (esp32-c3-devkitm-1, 4 MB,
    USB-CDC).
    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
2026-10-02 Deep Sleep nach Inaktivitaet mit Aufwecken per Knopf
    - Firmware: nach SLEEP_TIMEOUT_MS (Standard 60s) ohne laufende Aufnahme Deep
    Sleep; Aufwecken ueber WAKE_BUTTON_PIN (active low). Chip-spezifische
    Weckquelle: ext0 auf ESP32/S3 (RTC-GPIO, z.B. BOOT/GPIO0), gpio-wakeup auf
    C3/C6/H2. Inaktivitaetstimer via last_active_ms (Reset bei Start/Stop + Boot).
    - config.h.example: ENABLE_DEEP_SLEEP, SLEEP_TIMEOUT_MS, WAKE_BUTTON_PIN mit
    Hinweis, dass der C3 nur GPIO0..5 wecken kann (BOOT/GPIO9 NICHT) -> C3-Block
    auf GPIO1 als Toggle+Weck-Knopf angepasst.
    - README: Abschnitt "Stromsparen: Deep Sleep" mit Board-Tabelle, Pull-up-Hinweis
    und Verhalten (erster Druck weckt nur, dann starten).
    C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
    [main.cpp]
2026-10-02 3D-Gehaeuse (FreeCAD + STL) fuer ESP32-C3 Super Mini + INMP441 + Akku
    - hardware/case/meeting_ki_case.FCMacro: parametrisches FreeCAD-Macro (Part-API)
    baut Unterteil + Deckel und exportiert STLs. Alle Masse oben einstellbar.
    - generate_case.py: FreeCAD-unabhaengiger STL-Generator (trimesh/manifold3d) mit
    identischen Massen.
    - Fertige base.stl / lid.stl / assembly_preview.stl (watertight) + preview.png.
    - README mit Aufbau (Akku unten, ESP auf Schienen, Mic am Deckel), USB-C-
    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
    [assembly_preview.stl, base.stl, lid.stl]
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
